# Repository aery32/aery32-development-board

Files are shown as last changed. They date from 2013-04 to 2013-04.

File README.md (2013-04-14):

Aery32 Development Board
========================

<br /><span xmlns:dct="http://purl.org/dc/terms/" property="dct:title">Aery32 Development Board</span> by <a xmlns:cc="http://creativecommons.org/ns#" href="www.muiku.com" property="cc:attributionName" rel="cc:attributionURL">Muiku Oy</a> is licensed under a <a rel="license" href="http://creativecommons.org/licenses/by-sa/3.0/">Creative Commons Attribution-ShareAlike 3.0 Unported License</a>.<br />Permissions beyond the scope of this license may be available at <a xmlns:cc="http://creativecommons.org/ns#" href="www.muiku.com" rel="cc:morePermissions">www.muiku.com</a>.

Copyright (c) 2012, Muiku Oy
All rights reserved.

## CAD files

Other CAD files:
aery32_3dmodel.skp

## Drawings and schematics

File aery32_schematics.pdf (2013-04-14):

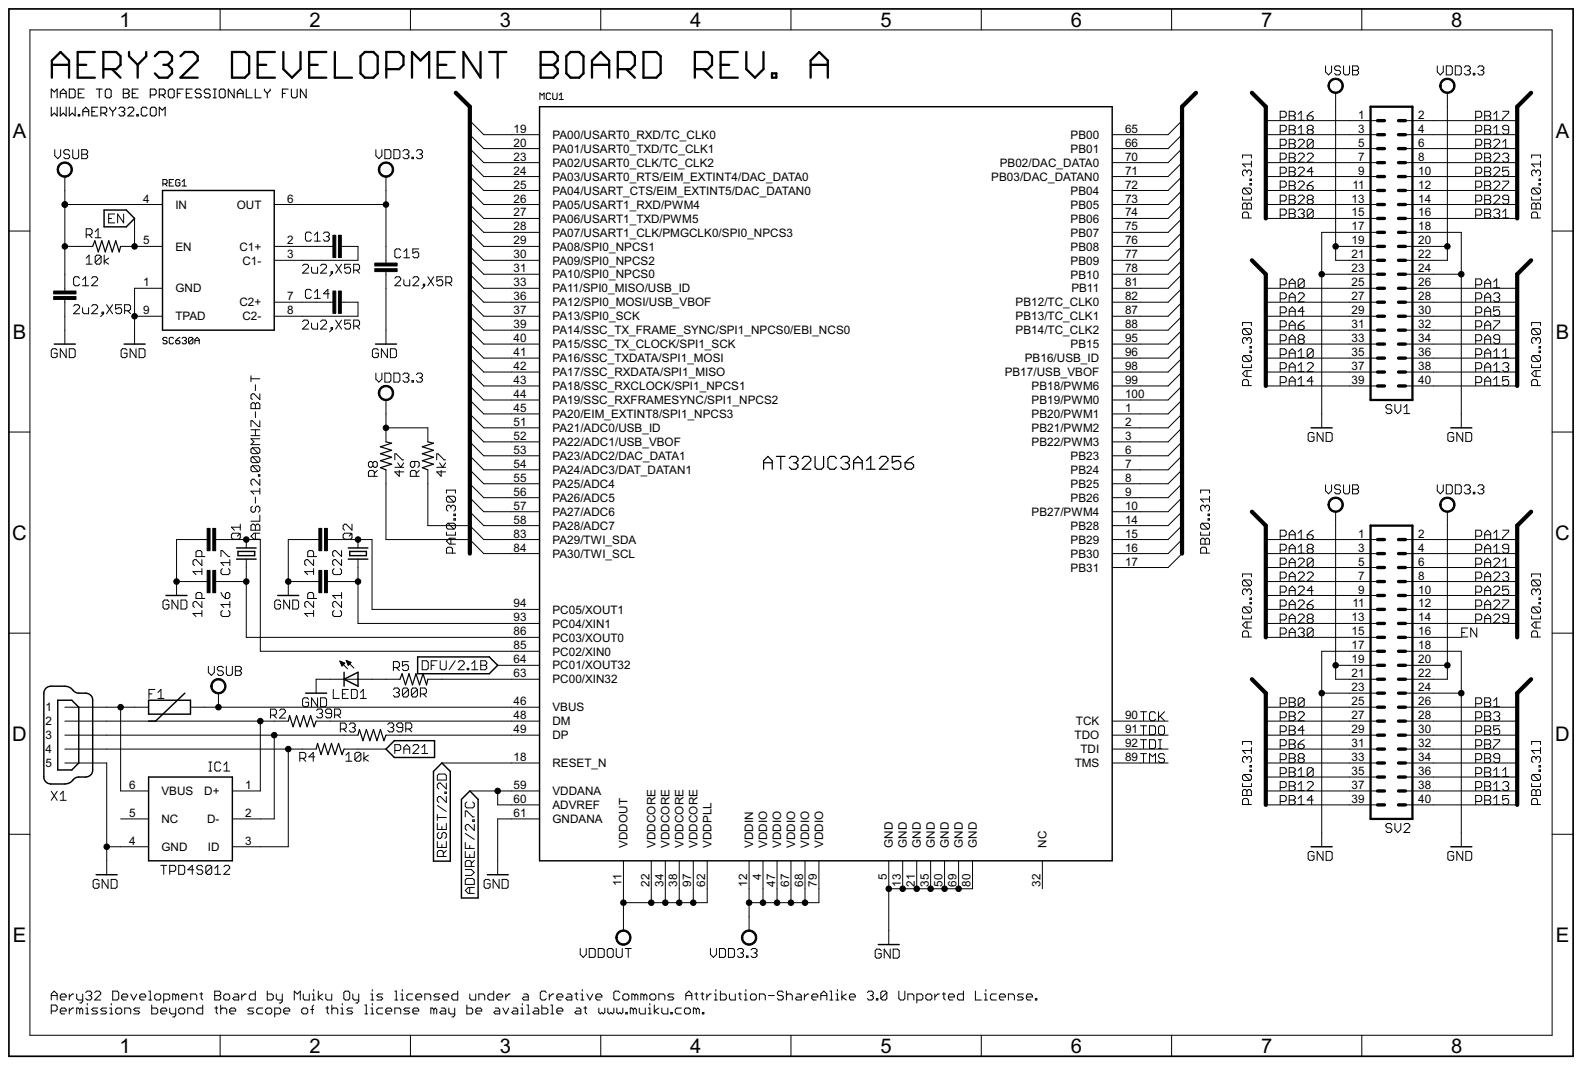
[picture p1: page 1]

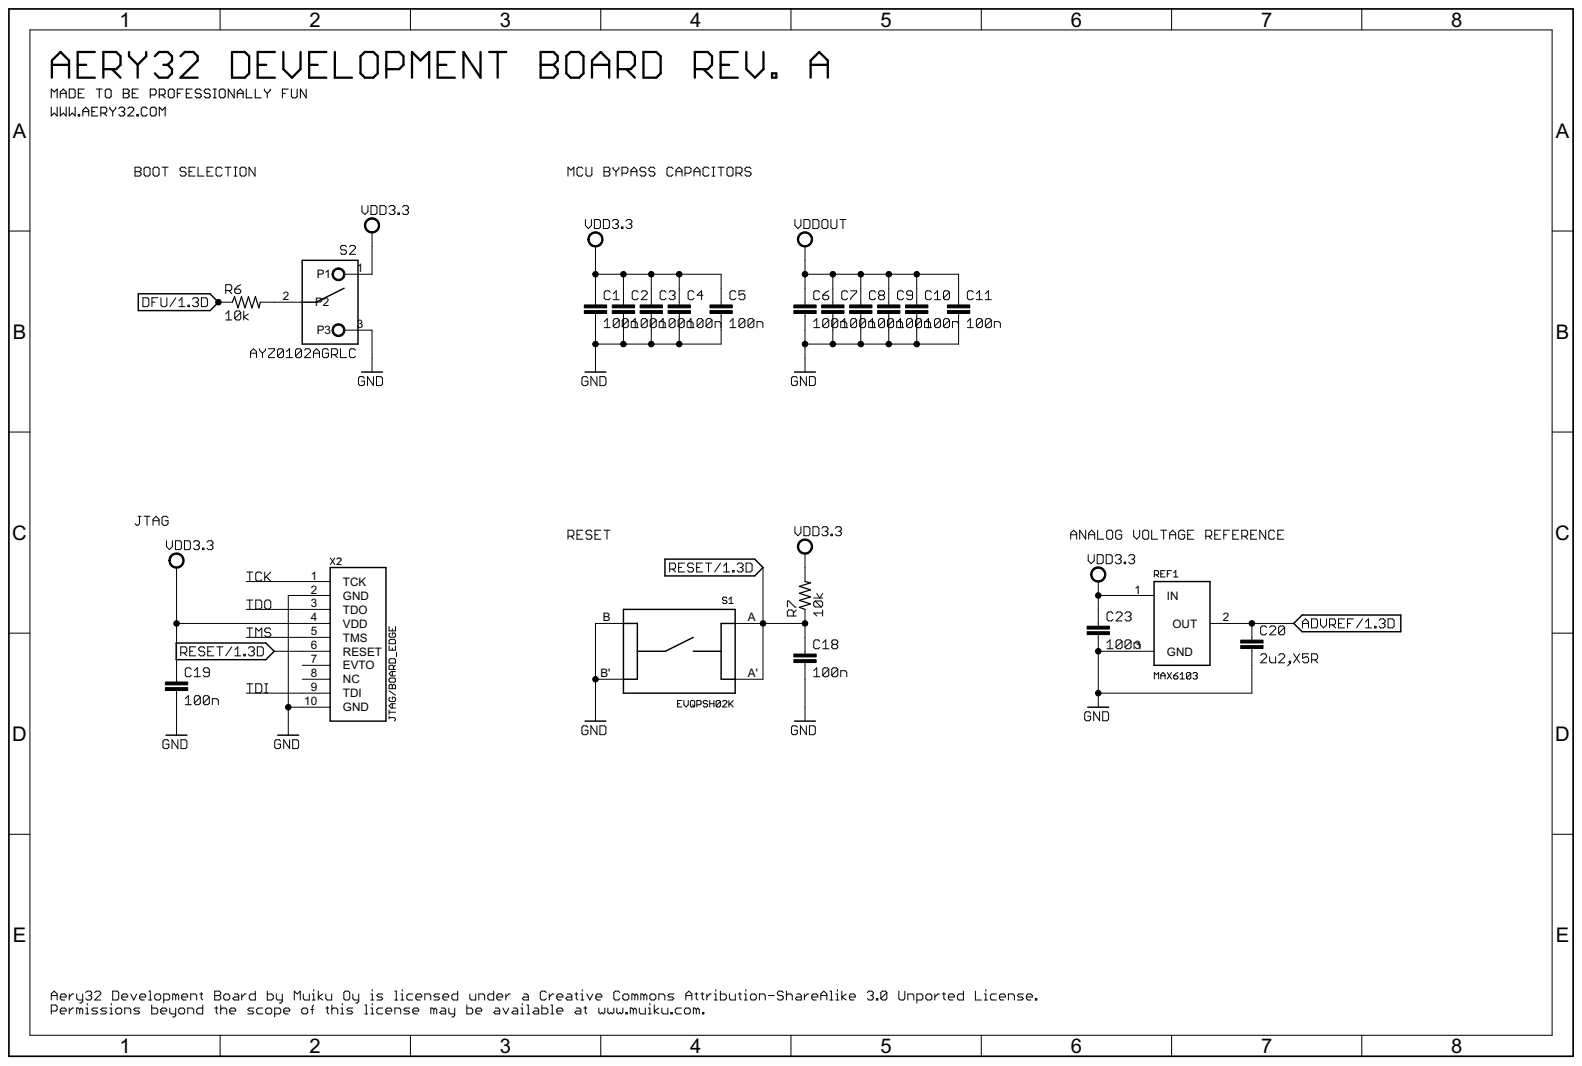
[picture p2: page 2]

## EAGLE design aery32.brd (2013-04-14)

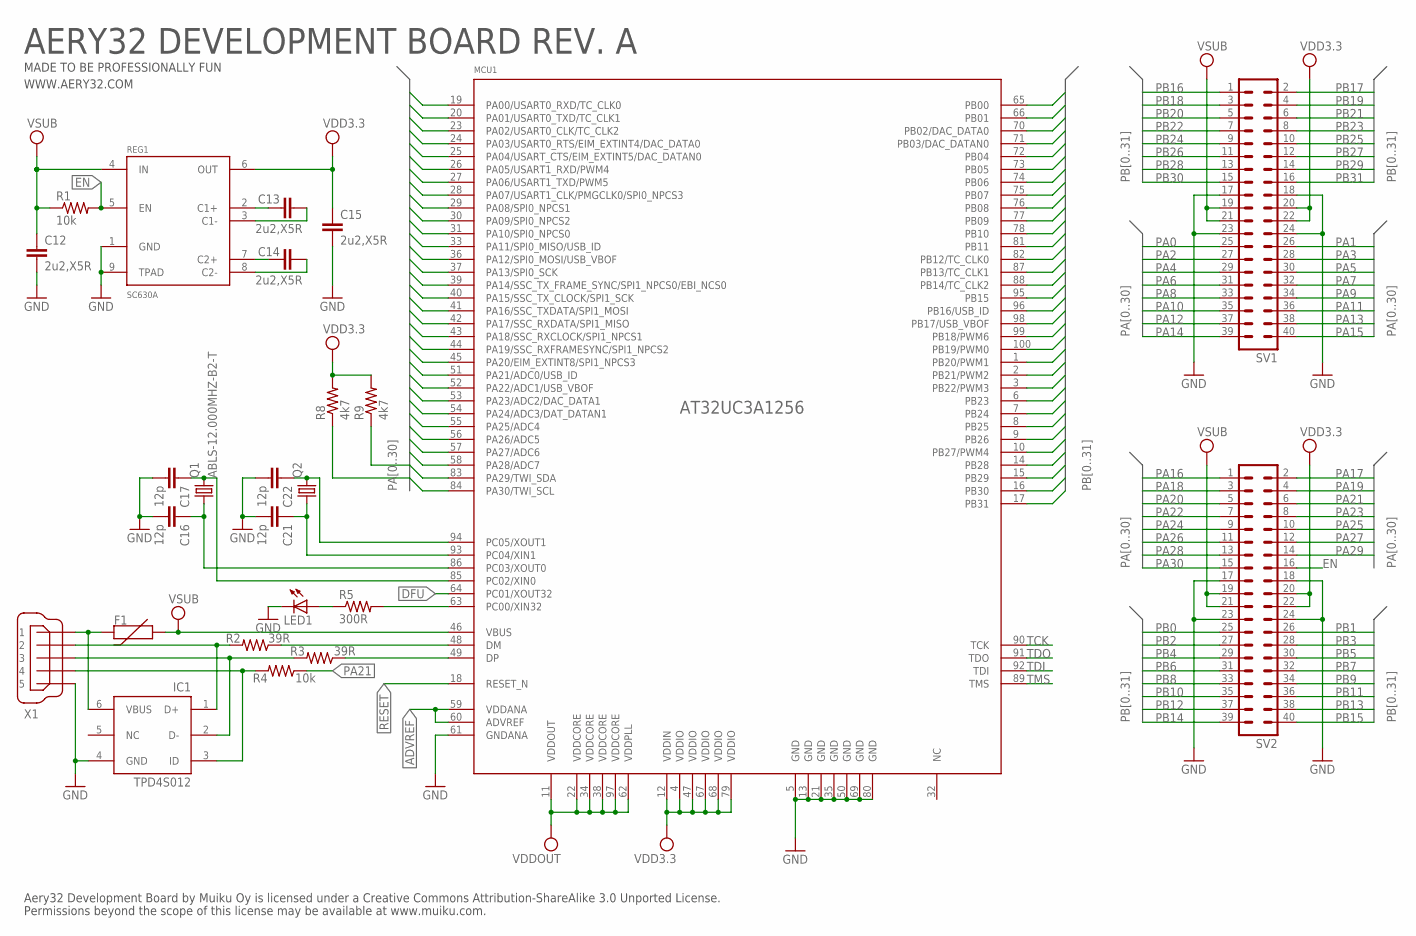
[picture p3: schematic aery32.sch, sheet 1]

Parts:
C12, C13, C14, C15: 2u2,X5R; C0402
C16, C17, C21, C22: 12p; C0402
F1: PTCSMD; PTC-1206
IC1: TPD4S012; DRY
LED1: LEDCHIPLED_0805; CHIPLED_0805
MCU1: AT32UC3A1256; TQFP100; DIGIKEY AT32UC3A1256-AUT-ND
Q1: ABLS-12.000MHZ-B2-T; HC49UP; DIGIKEY 535-9067-1-ND
Q2: CRYSTALTC38H; TC38H
R1, R4: 10k; R0402
R2, R3: 39R; R0402
R5: 300R; R0402
R8, R9: 4k7; R0402
REG1: SC630A; MLPD-UT-8
SV1, SV2: MA20-2
X1: USBMINI-B; MINIUSB

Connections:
ADVREF: MCU1.59 (VDDANA), MCU1.60 (ADVREF); also elsewhere on the board
DFU: MCU1.64 (PC01/XOUT32); also elsewhere on the board
EN: R1.2, REG1.5 (EN), SV2.16
GND: C12.2, C15.2, C16.2, C17.2, C21.2, C22.2, IC1.4 (GND), LED1.C, MCU1.5 (GND), MCU1.13 (GND), MCU1.21 (GND), MCU1.35 (GND), MCU1.50 (GND), MCU1.61 (GNDANA), MCU1.69 (GND), MCU1.80 (GND), REG1.1 (GND), REG1.9 (TPAD), SV1.17, SV1.18, SV1.23, SV1.24, SV2.17, SV2.18, SV2.23, SV2.24, X1.5; also elsewhere on the board
unnamed: C13.1, REG1.2 (C1+)
unnamed: MCU1.63 (PC00/XIN32), R5.2
unnamed: IC1.3 (ID), R4.2, X1.4
unnamed: MCU1.48 (DM), R2.1
unnamed: MCU1.49 (DP), R3.1
unnamed: IC1.2 (D-), R3.2, X1.3
unnamed: IC1.1 (D+), R2.2, X1.2
unnamed: LED1.A, R5.1
unnamed: F1.2, IC1.6 (VBUS), X1.1
unnamed: C13.2, REG1.3 (C1-)
unnamed: C14.1, REG1.7 (C2+)
unnamed: C14.2, REG1.8 (C2-)
unnamed: C16.1, MCU1.86 (PC03/XOUT0), Q1.1
unnamed: C22.1, MCU1.94 (PC05/XOUT1), Q2.2
unnamed: C17.1, MCU1.85 (PC02/XIN0), Q1.2
unnamed: C21.1, MCU1.93 (PC04/XIN1), Q2.1
PA0: MCU1.19 (PA00/USART0_RXD/TC_CLK0), SV1.25
PA1: MCU1.20 (PA01/USART0_TXD/TC_CLK1), SV1.26
PA2: MCU1.23 (PA02/USART0_CLK/TC_CLK2), SV1.27
PA3: MCU1.24 (PA03/USART0_RTS/EIM_EXTINT4/DAC_DATA0), SV1.28
PA4: MCU1.25 (PA04/USART_CTS/EIM_EXTINT5/DAC_DATAN0), SV1.29
PA5: MCU1.26 (PA05/USART1_RXD/PWM4), SV1.30
PA6: MCU1.27 (PA06/USART1_TXD/PWM5), SV1.31
PA7: MCU1.28 (PA07/USART1_CLK/PMGCLK0/SPI0_NPCS3), SV1.32
PA8: MCU1.29 (PA08/SPI0_NPCS1), SV1.33
PA9: MCU1.30 (PA09/SPI0_NPCS2), SV1.34
PA10: MCU1.31 (PA10/SPI0_NPCS0), SV1.35
PA11: MCU1.33 (PA11/SPI0_MISO/USB_ID), SV1.36
PA12: MCU1.36 (PA12/SPI0_MOSI/USB_VBOF), SV1.37
PA13: MCU1.37 (PA13/SPI0_SCK), SV1.38
PA14: MCU1.39 (PA14/SSC_TX_FRAME_SYNC/SPI1_NPCS0/EBI_N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), SV1.39
PA15: MCU1.40 (PA15/SSC_TX_CLOCK/SPI1_SCK), SV1.40
PA16: MCU1.41 (PA16/SSC_TXDATA/SPI1_MOSI), SV2.1
PA17: MCU1.42 (PA17/SSC_RXDATA/SPI1_MISO), SV2.2
PA18: MCU1.43 (PA18/SSC_RXCLOCK/SPI1_NPCS1), SV2.3
PA19: MCU1.44 (PA19/SSC_RXFRAMESYNC/SPI1_NPCS2), SV2.4
PA20: MCU1.45 (PA20/EIM_EXTINT8/SPI1_NPCS3), SV2.5
PA21: MCU1.51 (PA21/ADC0/USB_ID), R4.1, SV2.6
PA22: MCU1.52 (PA22/ADC1/USB_VBOF), SV2.7
PA23: MCU1.53 (PA23/ADC2/DAC_DATA1), SV2.8
PA24: MCU1.54 (PA24/ADC3/DAT_DATAN1), SV2.9
PA25: MCU1.55 (PA25/ADC4), SV2.10
PA26: MCU1.56 (PA26/ADC5), SV2.11
PA27: MCU1.57 (PA27/ADC6), SV2.12
PA28: MCU1.58 (PA28/ADC7), SV2.13
PA29: MCU1.83 (PA29/TWI_SDA), R9.1, SV2.14
PA30: MCU1.84 (PA30/TWI_SCL), R8.1, SV2.15
PB0: MCU1.65 (PB00), SV2.25
PB1: MCU1.66 (PB01), SV2.26
PB2: MCU1.70 (PB02/DAC_DATA0), SV2.27
PB3: MCU1.71 (PB03/DAC_DATAN0), SV2.28
PB4: MCU1.72 (PB04), SV2.29
PB5: MCU1.73 (PB05), SV2.30
PB6: MCU1.74 (PB06), SV2.31
PB7: MCU1.75 (PB07), SV2.32
PB8: MCU1.76 (PB08), SV2.33
PB9: MCU1.77 (PB09), SV2.34
PB10: MCU1.78 (PB10), SV2.35
PB11: MCU1.81 (PB11), SV2.36
PB12: MCU1.82 (PB12/TC_CLK0), SV2.37
PB13: MCU1.87 (PB13/TC_CLK1), SV2.38
PB14: MCU1.88 (PB14/TC_CLK2), SV2.39
PB15: MCU1.95 (PB15), SV2.40
PB16: MCU1.96 (PB16/USB_ID), SV1.1
PB17: MCU1.98 (PB17/USB_VBOF), SV1.2
PB18: MCU1.99 (PB18/PWM6), SV1.3
PB19: MCU1.100 (PB19/PWM0), SV1.4
PB20: MCU1.1 (PB20/PWM1), SV1.5
PB21: MCU1.2 (PB21/PWM2), SV1.6
PB22: MCU1.3 (PB22/PWM3), SV1.7
PB23: MCU1.6 (PB23), SV1.8
PB24: MCU1.7 (PB24), SV1.9
PB25: MCU1.8 (PB25), SV1.10
PB26: MCU1.9 (PB26), SV1.11
PB27: MCU1.10 (PB27/PWM4), SV1.12
PB28: MCU1.14 (PB28), SV1.13
PB29: MCU1.15 (PB29), SV1.14
PB30: MCU1.16 (PB30), SV1.15
PB31: MCU1.17 (PB31), SV1.16
RESET: MCU1.18 (RESET_N); also elsewhere on the board
TCK: MCU1.90 (TCK); also elsewhere on the board
TDI: MCU1.92 (TDI); also elsewhere on the board
TDO: MCU1.91 (TDO); also elsewhere on the board
TMS: MCU1.89 (TMS); also elsewhere on the board
VBUS: C12.1, F1.1, MCU1.46 (VBUS), R1.1, REG1.4 (IN), SV1.19, SV1.21, SV2.19, SV2.21
VDD3.3: C15.1, MCU1.4 (VDDIO), MCU1.12 (VDDIN), MCU1.47 (VDDIO), MCU1.67 (VDDIO), MCU1.68 (VDDIO), MCU1.79 (VDDIO), R8.2, R9.2, REG1.6 (OUT), SV1.20, SV1.22, SV2.20, SV2.22; also elsewhere on the board
VDDOUT: MCU1.11 (VDDOUT), MCU1.22 (VDDCORE), MCU1.34 (VDDCORE), MCU1.38 (VDDCORE), MCU1.62 (VDDPLL), MCU1.97 (VDDCORE); also elsewhere on the board

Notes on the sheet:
Aery32 Development Board by Muiku Oy is licensed under a Creative Commons Attribution-ShareAlike 3.0 Unported License.
Permissions beyond the scope of this license may be available at www.muiku.com.
AERY32 DEVELOPMENT BOARD REV. A
MADE TO BE PROFESSIONALLY FUN
WWW.AERY32.COM

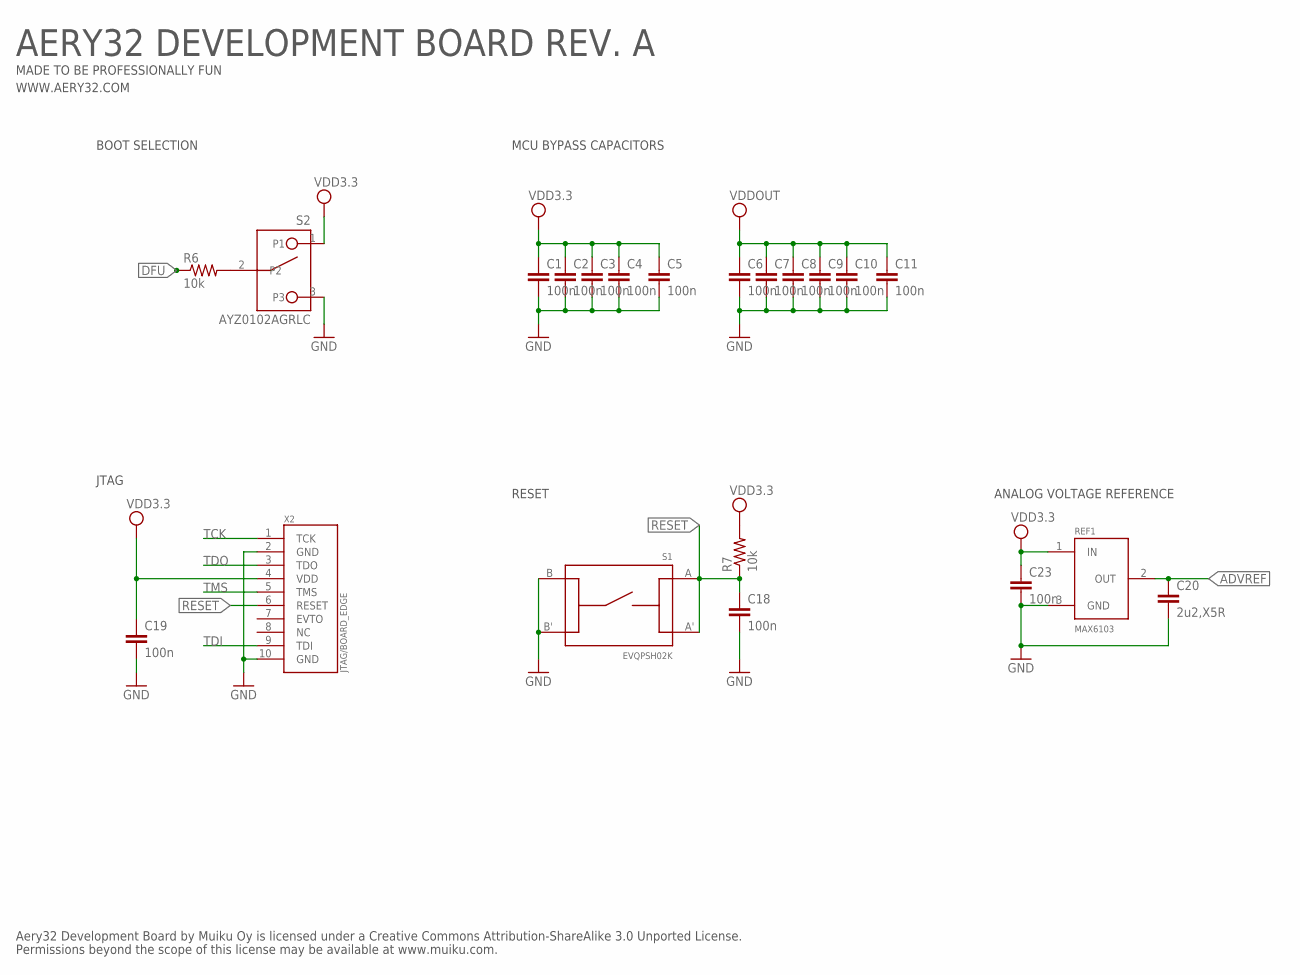
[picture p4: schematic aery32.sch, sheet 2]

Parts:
C1, C2, C3, C4, C5, C6, C7, C8, C9, C10, C11, C18, C19, C23: 100n; C0402
C20: 2u2,X5R; C0402
R6, R7: 10k; R0402
REF1: MAX6103; SOT23
S1: EVQPSH02K
S2: AYZ0102AGRLC
X2: JTAG/BOARD_EDGE

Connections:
ADVREF: C20.1, REF1.2 (OUT); also elsewhere on the board
DFU: R6.1; also elsewhere on the board
GND: C1.2, C2.2, C3.2, C4.2, C5.2, C6.2, C7.2, C8.2, C9.2, C10.2, C11.2, C18.2, C19.2, C20.2, C23.2, REF1.3 (GND), S1.B, S1.B', S2.3, X2.2 (GND), X2.10 (GND); also elsewhere on the board
unnamed: R6.2, S2.2
RESET: C18.1, R7.1, S1.A, S1.A', X2.6 (RESET); also elsewhere on the board
TCK: X2.1 (TCK); also elsewhere on the board
TDI: X2.9 (TDI); also elsewhere on the board
TDO: X2.3 (TDO); also elsewhere on the board
TMS: X2.5 (TMS); also elsewhere on the board
VDD3.3: C1.1, C2.1, C3.1, C4.1, C5.1, C19.1, C23.1, R7.2, REF1.1 (IN), S2.1, X2.4 (VDD); also elsewhere on the board
VDDOUT: C6.1, C7.1, C8.1, C9.1, C10.1, C11.1; also elsewhere on the board

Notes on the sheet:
MCU BYPASS CAPACITORS
ANALOG VOLTAGE REFERENCE
BOOT SELECTION
JTAG
RESET
Aery32 Development Board by Muiku Oy is licensed under a Creative Commons Attribution-ShareAlike 3.0 Unported License.
Permissions beyond the scope of this license may be available at www.muiku.com.
AERY32 DEVELOPMENT BOARD REV. A
MADE TO BE PROFESSIONALLY FUN
WWW.AERY32.COM

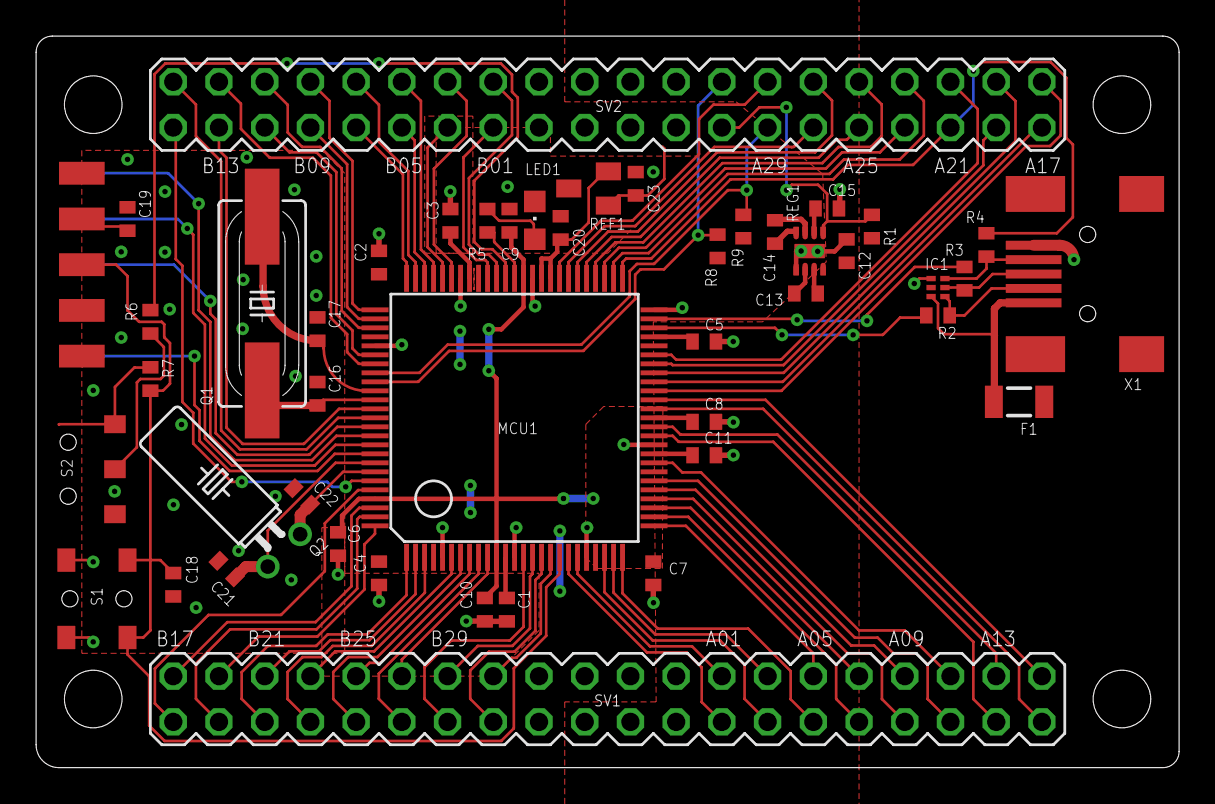
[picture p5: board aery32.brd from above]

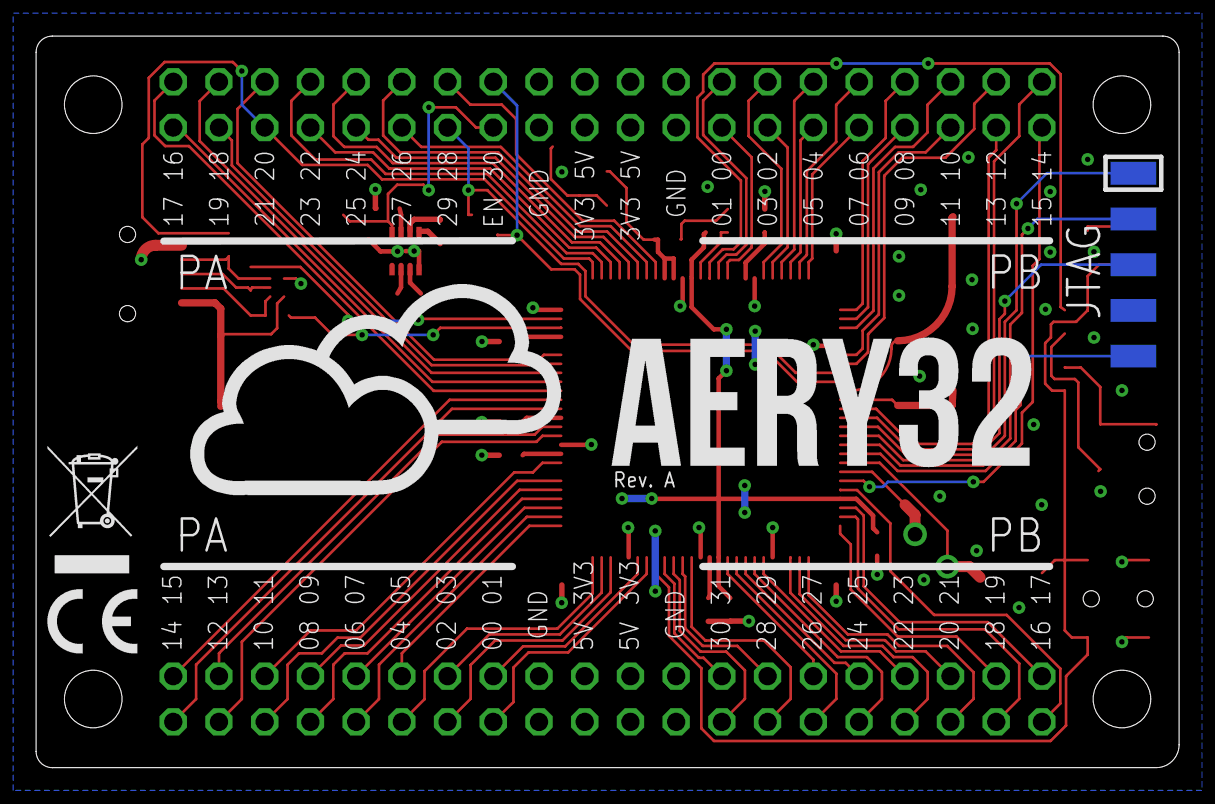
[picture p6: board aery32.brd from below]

Board: 2 copper layers, 63.5 x 40.6 mm, 49 parts (4 on the bottom side), 92 nets.

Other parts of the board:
U$16: CE/5MM-WIDE
U$18: WEEE/5MM-WIDE
U$19: LOGO/AERY32
